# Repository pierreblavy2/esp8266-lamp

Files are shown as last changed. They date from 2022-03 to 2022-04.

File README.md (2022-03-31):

# esp8266-lamp
A wifi controllable RGB light, based on esp8266.
The default access point ssid is <code>lamp</code>, the password is <code>magicword</code>, and the adress is <code>http://192.168.4.1</code>.
NOTE the curent version works only with http, not https.

# The project contains 
- the PCB design (kicad and gerber) CC-BY-SA 3.0
- the 3D printer files (3d) CC-BY-SA 3.0
- the arduino code (arduino) Some file MIT, some GPL-3.0, see details in Licenses.txt
- For details about licences, see Licenses.txt

# Images

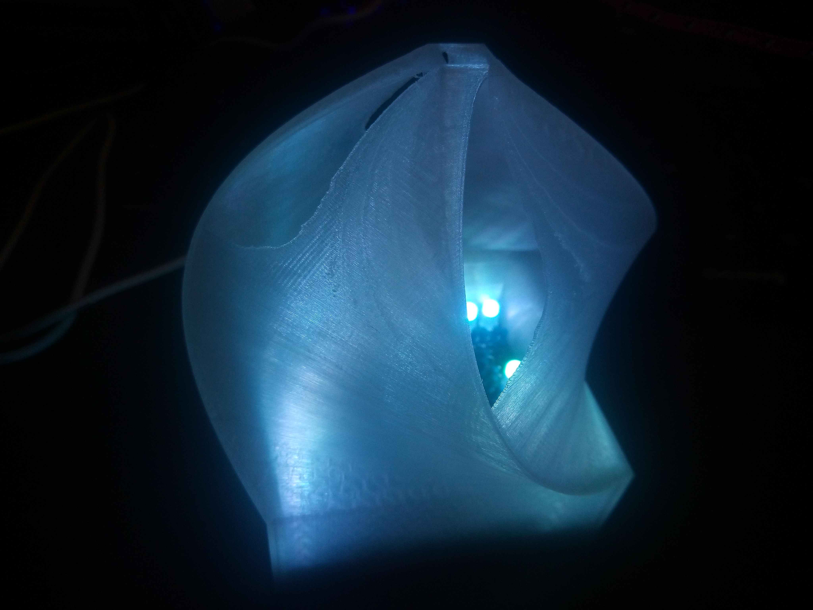
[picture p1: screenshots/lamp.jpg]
Lamp

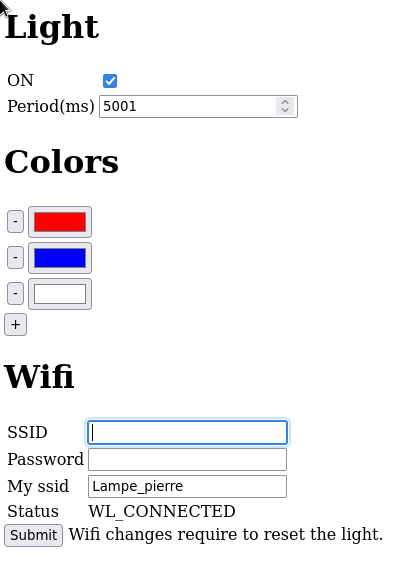
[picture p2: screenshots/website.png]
Website


# Thanks
Thank a lot to Syntax and Uru, who helped a lot for this project!

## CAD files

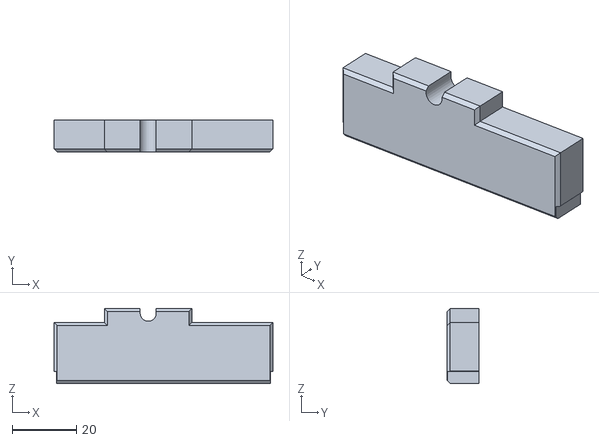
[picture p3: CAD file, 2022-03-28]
3d/lampe-cap.stl
68.1 x 10.0 x 23.4

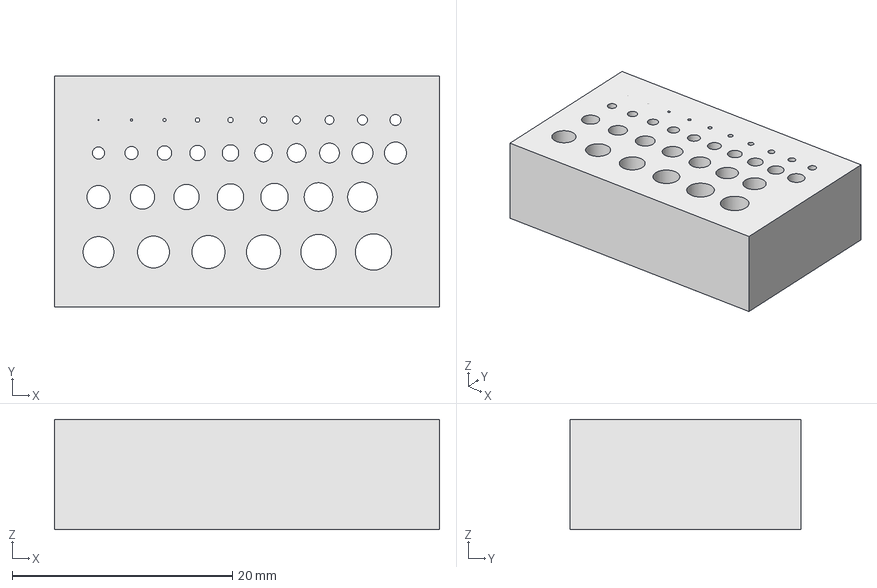
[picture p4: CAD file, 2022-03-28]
3d/gauge.FCStd
35.0 x 21.0 x 10.0 mm

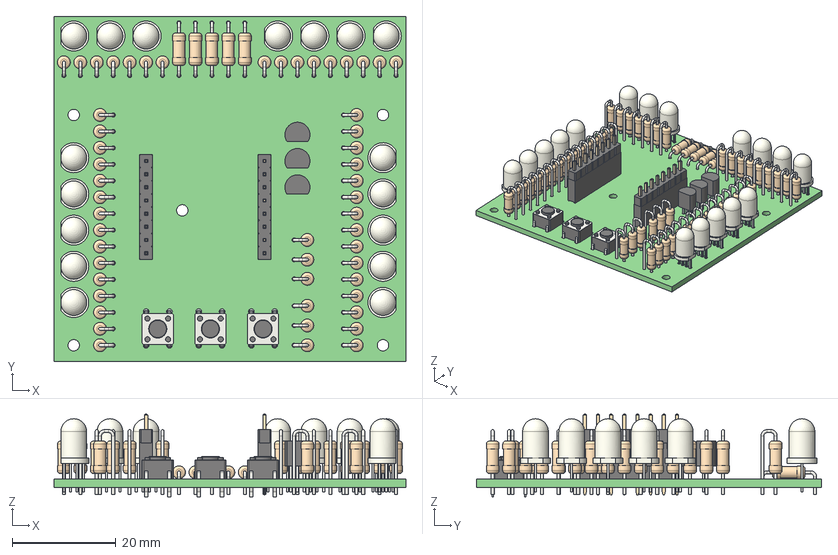
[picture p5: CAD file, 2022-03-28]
3d/lampe.step
67.9 x 66.7 x 16.0 mm

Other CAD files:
3d/gauge.stl
3d/lampe.FCStd

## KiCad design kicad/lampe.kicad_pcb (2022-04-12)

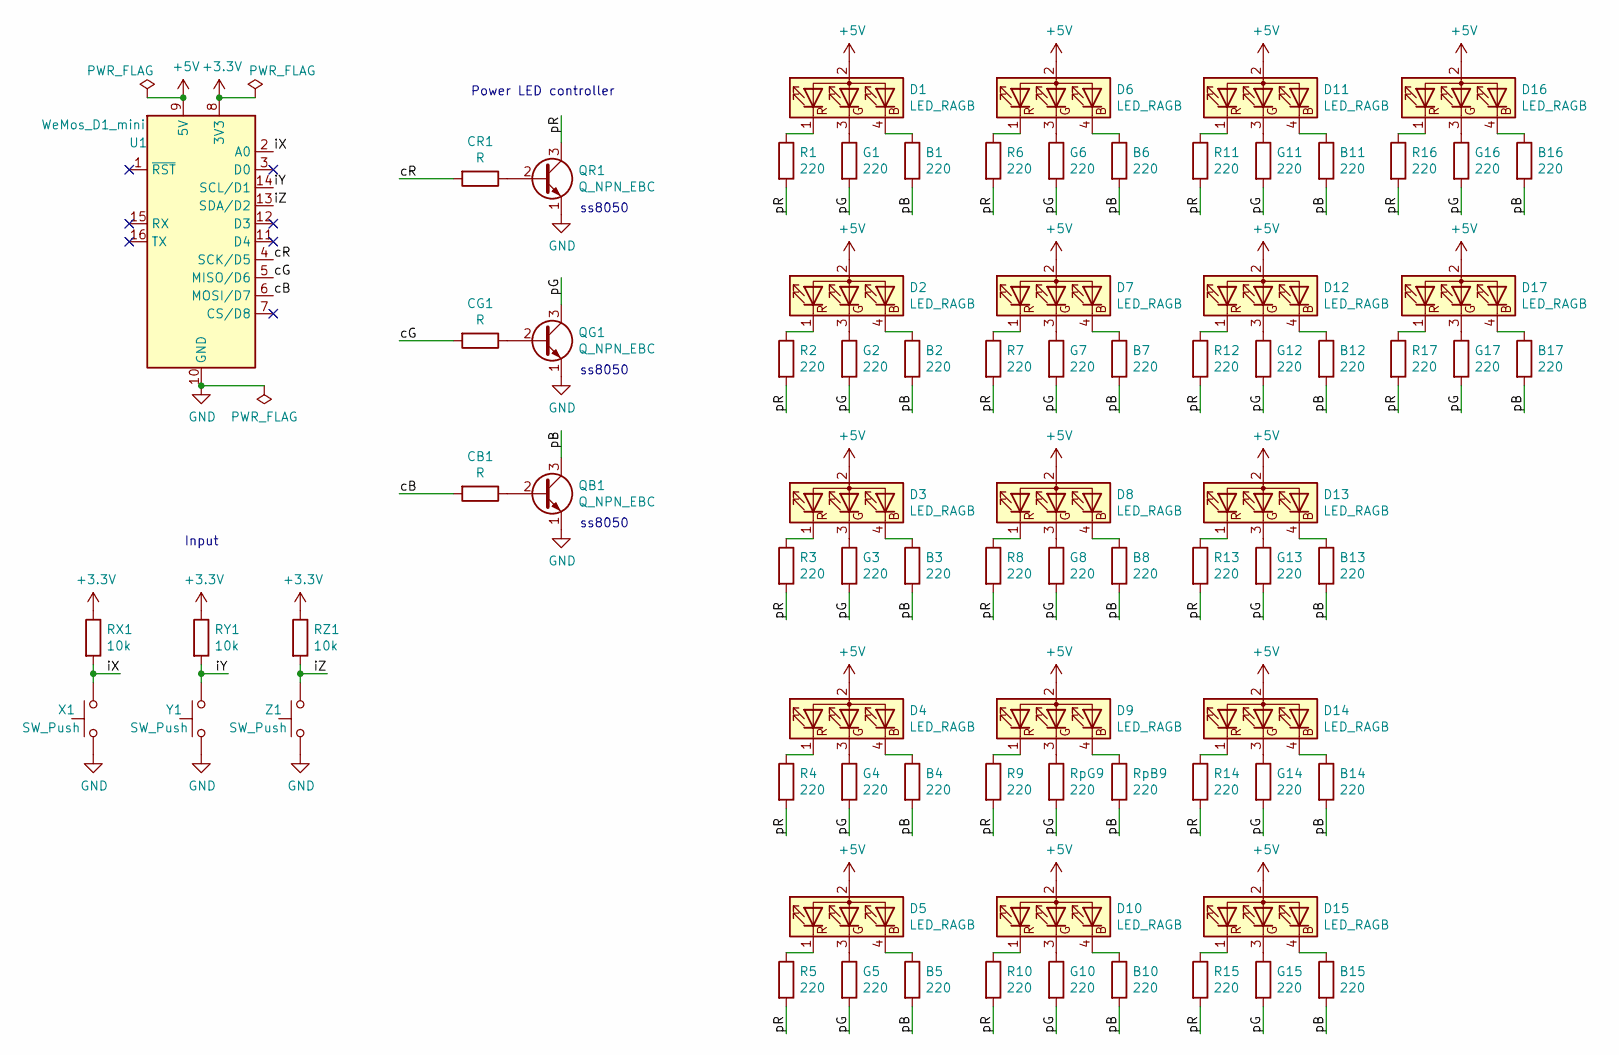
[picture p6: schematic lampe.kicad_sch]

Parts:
B1, B2, B3, B4, B5, B6, B7, B8, B10, B11, B12, B15, B16, B17: 220; R_Axial_DIN0207_L6.3mm_D2.5mm_P2.54mm_Vertical
B13, B14: 220; R_Axial_DIN0207_L6.3mm_D2.5mm_P10.16mm_Horizontal
CB1: R; R_Axial_DIN0207_L6.3mm_D2.5mm_P2.54mm_Vertical
CG1: R; R_Axial_DIN0207_L6.3mm_D2.5mm_P2.54mm_Vertical
CR1: R; R_Axial_DIN0207_L6.3mm_D2.5mm_P2.54mm_Vertical
D1, D2, D3, D4, D5, D6, D7, D8, D9, D10, D11, D12, D13, D14, D15, D16, D17: LED_RAGB; LED_RAGB_5mm_v2
G1, G2, G3, G4, G5, G6, G7, G8, G10, G11, G12, G15, G16, G17: 220; R_Axial_DIN0207_L6.3mm_D2.5mm_P2.54mm_Vertical
G13, G14: 220; R_Axial_DIN0207_L6.3mm_D2.5mm_P10.16mm_Horizontal
QB1: Q_NPN_EBC; Q_NPN_EBC_TO-92_v2
QG1: Q_NPN_EBC; Q_NPN_EBC_TO-92_v2
QR1: Q_NPN_EBC; Q_NPN_EBC_TO-92_v2
R1, R2, R3, R4, R5, R6, R7, R8, R9, R10, R11, R12, R13, R15, R16, R17: 220; R_Axial_DIN0207_L6.3mm_D2.5mm_P2.54mm_Vertical
R14: 220; R_Axial_DIN0207_L6.3mm_D2.5mm_P10.16mm_Horizontal
RX1: 10k; R_Axial_DIN0207_L6.3mm_D2.5mm_P2.54mm_Vertical
RY1: 10k; R_Axial_DIN0207_L6.3mm_D2.5mm_P2.54mm_Vertical
RZ1: 10k; R_Axial_DIN0207_L6.3mm_D2.5mm_P2.54mm_Vertical
RpB9: 220; R_Axial_DIN0207_L6.3mm_D2.5mm_P2.54mm_Vertical
RpG9: 220; R_Axial_DIN0207_L6.3mm_D2.5mm_P2.54mm_Vertical
U1: WeMos_D1_mini; WEMOS_D1_mini_light
X1: SW_Push; SW_PUSH_6mm
Y1: SW_Push; SW_PUSH_6mm
Z1: SW_Push; SW_PUSH_6mm

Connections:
+3V3: RX1.1, RY1.1, RZ1.1, U1.8 (3V3)
+5V: D1.2 (A), D2.2 (A), D3.2 (A), D4.2 (A), D5.2 (A), D6.2 (A), D7.2 (A), D8.2 (A), D9.2 (A), D10.2 (A), D11.2 (A), D12.2 (A), D13.2 (A), D14.2 (A), D15.2 (A), D16.2 (A), D17.2 (A), U1.9 (5V)
/cB: CB1.2, U1.6 (MOSI/D7)
/cG: CG1.2, U1.5 (MISO/D6)
/cR: CR1.2, U1.4 (SCK/D5)
/iX: RX1.2, U1.2 (A0), X1.2
/iY: RY1.2, U1.14 (SCL/D1), Y1.2
/iZ: RZ1.2, U1.13 (SDA/D2), Z1.2
/pB: B1.2, B2.2, B3.2, B4.2, B5.2, B6.2, B7.2, B8.2, B10.2, B11.2, B12.2, B13.2, B14.2, B15.2, B16.2, B17.2, QB1.3 (C), RpB9.2
/pG: G1.2, G2.2, G3.2, G4.2, G5.2, G6.2, G7.2, G8.2, G10.2, G11.2, G12.2, G13.2, G14.2, G15.2, G16.2, G17.2, QG1.3 (C), RpG9.2
/pR: QR1.3 (C), R1.2, R2.2, R3.2, R4.2, R5.2, R6.2, R7.2, R8.2, R9.2, R10.2, R11.2, R12.2, R13.2, R14.2, R15.2, R16.2, R17.2
GND: QB1.1 (E), QG1.1 (E), QR1.1 (E), U1.10 (GND), X1.1, Y1.1, Z1.1
unnamed: B1.1, D1.4 (BK)
unnamed: B2.1, D2.4 (BK)
unnamed: B3.1, D3.4 (BK)
unnamed: B4.1, D4.4 (BK)
unnamed: B5.1, D5.4 (BK)
unnamed: B6.1, D6.4 (BK)
unnamed: B7.1, D7.4 (BK)
unnamed: B8.1, D8.4 (BK)
unnamed: B10.1, D10.4 (BK)
unnamed: B11.1, D11.4 (BK)
unnamed: B12.1, D12.4 (BK)
unnamed: B13.1, D13.4 (BK)
unnamed: B14.1, D14.4 (BK)
unnamed: B15.1, D15.4 (BK)
unnamed: B16.1, D16.4 (BK)
unnamed: B17.1, D17.4 (BK)
unnamed: CB1.1, QB1.2 (B)
unnamed: CG1.1, QG1.2 (B)
unnamed: CR1.1, QR1.2 (B)
unnamed: D1.1 (RK), R1.1
unnamed: D1.3 (GK), G1.1
unnamed: D2.1 (RK), R2.1
unnamed: D2.3 (GK), G2.1
unnamed: D3.1 (RK), R3.1
unnamed: D3.3 (GK), G3.1
unnamed: D4.1 (RK), R4.1
unnamed: D4.3 (GK), G4.1
unnamed: D5.1 (RK), R5.1
unnamed: D5.3 (GK), G5.1
unnamed: D6.1 (RK), R6.1
unnamed: D6.3 (GK), G6.1
unnamed: D7.1 (RK), R7.1
unnamed: D7.3 (GK), G7.1
unnamed: D8.1 (RK), R8.1
unnamed: D8.3 (GK), G8.1
unnamed: D9.1 (RK), R9.1
unnamed: D9.3 (GK), RpG9.1
unnamed: D9.4 (BK), RpB9.1
unnamed: D10.1 (RK), R10.1
unnamed: D10.3 (GK), G10.1
unnamed: D11.1 (RK), R11.1
unnamed: D11.3 (GK), G11.1
unnamed: D12.1 (RK), R12.1
unnamed: D12.3 (GK), G12.1
unnamed: D13.1 (RK), R13.1
unnamed: D13.3 (GK), G13.1
unnamed: D14.1 (RK), R14.1
unnamed: D14.3 (GK), G14.1
unnamed: D15.1 (RK), R15.1
unnamed: D15.3 (GK), G15.1
unnamed: D16.1 (RK), R16.1
unnamed: D16.3 (GK), G16.1
unnamed: D17.1 (RK), R17.1
unnamed: D17.3 (GK), G17.1

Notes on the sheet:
Power LED controller
ss8050
Input

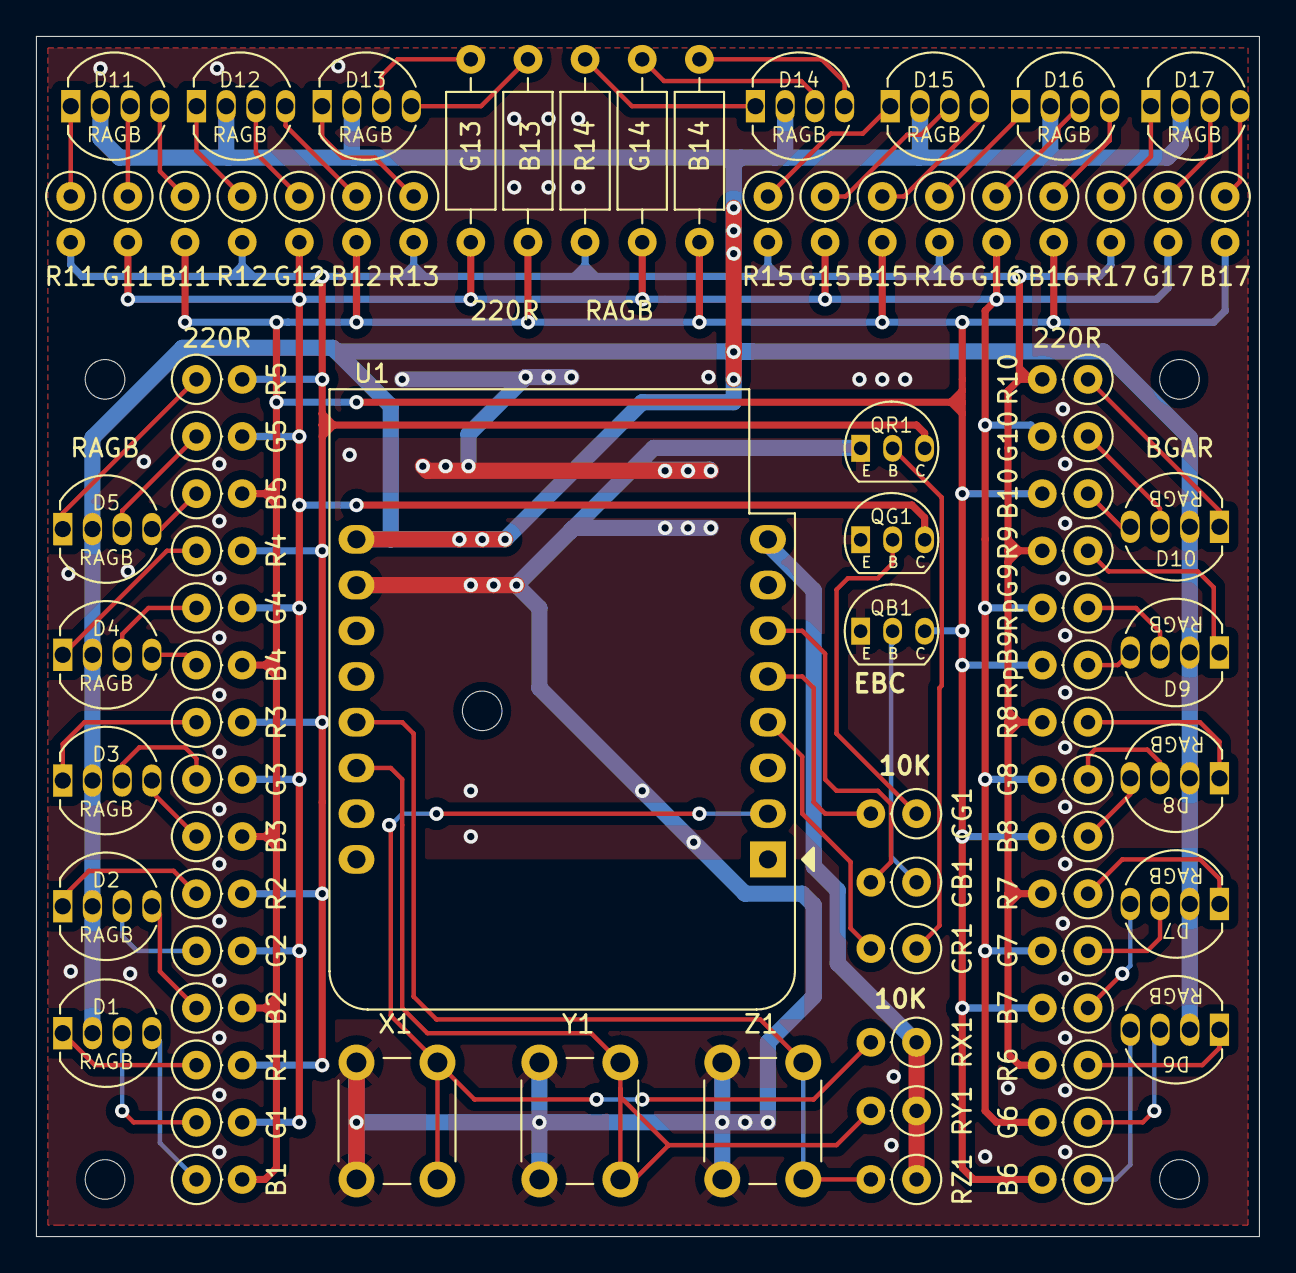
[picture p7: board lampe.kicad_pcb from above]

Board: 2 copper layers, 67.9 x 66.7 mm, 81 parts (0 on the bottom side), 66 nets.

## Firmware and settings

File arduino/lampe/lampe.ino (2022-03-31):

/* 
 * This file is part of the Lampe distribution (https://github.com/pierreblavy2).
 * Copyright (c) 2022 Pierre BLAVY.
 * 
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
 * You should have received a copy of the GNU General Public License 
 * along with this program. If not, see <http://www.gnu.org/licenses/>.
 */

#include "Lamp.hpp"
#include "Wifi.hpp"

#include "html_index.hpp"
#include "ArduinoJson.h"
#include "Timer.hpp"


#include <ESP8266WiFi.h>
#include <ESP8266WebServer.h>
#include <LittleFS.h>

//--- SWITCH wires ---
#define SW1 D1mini_A0
#define SW2 D1mini_D1
#define SW3 D1mini_D2

//--- data ---
Lamp lamp;
Wifi wifi;
ESP8266WebServer server(80);
decltype( millis() ) last_loop;

void fn_wifi_debug();
Timer wifi_debug(5000, fn_wifi_debug);


//--- web pages ---
//need server and lamp
#include "web_pages.hpp"


void setup() {
  //--- debug ---
  Serial.begin(9600);
  Serial.println("Setup");
 
  //---  wires ---
  pinMode(LED_R,OUTPUT);
  pinMode(LED_G,OUTPUT);
  pinMode(LED_B,OUTPUT);

  const Color tmp;
  analogWrite(LED_R, tmp.r);
  analogWrite(LED_G, tmp.g);
  analogWrite(LED_B, tmp.b);

  pinMode(SW1,INPUT);
  pinMode(SW2,INPUT);
  pinMode(SW3,INPUT);

  //--- data ---
  last_loop = millis();
  lamp.push_color(Color(255,0,0));
  lamp.push_color(Color(0,255,0));
  lamp.push_color(Color(0,0,255)); 
  


  //--- filesystem ---
  SPIFFSConfig filesystem_cfg;
  filesystem_cfg.setAutoFormat(true);
  SPIFFS.setConfig(filesystem_cfg);
  SPIFFS.begin();

  //--- load from filesystem ---
  lamp.load();
  wifi.load();
  Serial.print("MY_SSID (AP) :");Serial.println(wifi.get_my_ssid());
  Serial.print("SSID (ST) :");   Serial.println(wifi.get_ssid());

  
  //--- web pages & wifi ---
  //doc : https://siytek.com/esp8266-ap-and-station-mode/
  WiFi.mode(WIFI_AP_STA); //WIFI_AP_STA
  WiFi.softAP( wifi.get_my_ssid() , "magicword");//todo wifi.get_my_ssid()
  WiFi.begin(wifi.get_ssid()   , wifi.get_pass() );

  setup_web_pages();
  server.begin();


  //--- debug ---
  Serial.println("Setup OK");
}

void loop() {
   //compute delta
   auto now_v = millis();
   auto delta = now_v-last_loop;
   last_loop=now_v;

   //call run_loop
   lamp      .run_loop(delta);
   wifi_debug.run_loop(delta);

   //run server
   server.handleClient();
}



    

void fn_wifi_debug(){
  // Connected to WiFi
  Serial.println();
  Serial.print("Status : ");
  Serial.println( wifi_status_str( WiFi.status() ) );
  Serial.print("IP address ST : ");
  Serial.println(WiFi.localIP());
  Serial.print("IP address AP : ");
  Serial.println(WiFi.softAPIP());
}

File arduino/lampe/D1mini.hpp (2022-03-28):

/* 
 * This file is part of the Lampe distribution (https://github.com/pierreblavy2).
 * Copyright (c) 2022 Pierre BLAVY.
 * 
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
 * You should have received a copy of the GNU General Public License 
 * along with this program. If not, see <http://www.gnu.org/licenses/>.
 */
 
 
#ifndef D1MINI_HPP_
#define D1MINI_HPP_


//    RST       TX
// 17 A0        RX
// 16 D0        D1 5
// 14 D5        D2 4
// 12 D6        D3 0
// 13 D7        D4 2 LED (low=on)
// 15 D8        G
//    3v3 [usb] 5v


//Cardtype : LOLIN(wemos) D1 RD & mini
//Upload speed 921600
//CPU Frequency : 80MHz
//Flash Size : 4MB, ( FS:2MB OTA:~1019KB)
//Debug port : Disabled
//Debug level : None
//IwIP Variant : v2 Lower memory
//VTables : Flash
//Exceptions : Legacy (new ca return nullptr)
//Erase Flash : Only Sketch
//SSL Support : All SSL Ciphers (most compatible)


#define D1mini_PWM_MAX 1023

#define D1mini_D3 0
//1 is valid but is not an output pin
#define D1mini_D4  2
#define D1mini_LED 2
#define D1mini_LED_ON  LOW
#define D1mini_LED_OFF HIGH
#define D1mini_D2  4
#define D1mini_D1  5
// 6, 7, 8 , 9  //wdt reset
//10 is valid but is not an output pin
//11 wdt reset
#define D1mini_D6 12
#define D1mini_D7 13
#define D1mini_D5 14
#define D1mini_D8 15
#define D1mini_D0 16
#define D1mini_A0 17 //min0; max 1024

//18 is valid but is not an output pin
//19 is valid but is not an output pin

//---I2c ---
#define D1mini_SDA D1mini_D2
#define D1mini_SCL D1mini_D1

// SDA => D2
// SCL => D1



//--- CURSED PINS ---
// https://randomnerdtutorials.com/esp8266-pinout-reference-gpios/

/*
D0  GPIO16  no interrupt  no PWM or I2C support HIGH at boot
used to wake up from deep sleep
D1  GPIO5 OK  OK  often used as SCL (I2C)
D2  GPIO4 OK  OK  often used as SDA (I2C)
D3  GPIO0 pulled up OK  connected to FLASH button, boot fails if pulled LOW
D4  GPIO2 pulled up OK  HIGH at boot
connected to on-board LED, boot fails if pulled LOW
D5  GPIO14  OK  OK  SPI (SCLK)
D6  GPIO12  OK  OK  SPI (MISO)
D7  GPIO13  OK  OK  SPI (MOSI)
D8  GPIO15  pulled to GND OK  SPI (CS)
Boot fails if pulled HIGH
RX  GPIO3 OK  RX pin  HIGH at boot
TX  GPIO1 TX pin  OK  HIGH at boot
debug output at boot, boot fails if pulled LOW
*/




///--- PIN TEST CODE ---
/*
#define TEST_ME 17
void setup() {
  // put your setup code here, to run once:
    Serial.begin(115200);  //115200
  pinMode(TEST_ME, OUTPUT); digitalWrite(TEST_ME,LOW);
  Serial.println("END of setup");
}
void loop() {
  Serial.println("---Loop---");
  auto pin_test=[](pin_t pin, String s){
    Serial.print(s);
    Serial.print(" "); 
    Serial.println(pin);
    //blink
    digitalWrite(pin,HIGH);
    delay(250);
    digitalWrite(pin,LOW); 
    delay(250);
    pinMode(pin,INPUT);
    auto d = digitalRead(pin);
    auto a = analogRead(pin);
    Serial.print("digital:"); Serial.println(d);
    Serial.print("analog:"); Serial.println(a);
    pinMode(pin,OUTPUT);
    };
  
  pin_test(TEST_ME,"?");
}
*/

#endif

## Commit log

2022-03-28 Initial commit
    The lamp and the web site works
    [gauge.FCStd, gauge.stl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]
2022-04-12 +transistor and led footprint edit => spread the legs... euh
    [lampe-B_Cu.gbr, lampe-B_Mask.gbr, lampe-B_Paste.gbr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]

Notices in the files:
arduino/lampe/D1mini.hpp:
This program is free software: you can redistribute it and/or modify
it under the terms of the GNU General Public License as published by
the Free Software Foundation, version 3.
